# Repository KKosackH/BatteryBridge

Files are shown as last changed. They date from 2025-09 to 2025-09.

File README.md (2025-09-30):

# BatteryBridge  

The **BatteryBridge** is a PowerPath control circuit that ensures the essential electronics on the SwitchSystem PCB remain powered during grid disconnection.  

The SwitchSystem PCB only receives power when the home charger is in **IEC 61851 Control Pilot state C** (charging mode). When transitioning from charging to discharging, the PCB would normally lose power. The BatteryBridge solves this by automatically switching to battery supply, keeping the system running seamlessly.  

---

## Features  
- **Power continuity**: Maintains operation when the grid is disconnected or charger state changes.  
- **Integrated converters**: High-efficiency buck and boost converters for multiple voltage rails.  
- **PowerPath control**: Manages seamless switching between charger and battery.  
- **Battery charging**: Supports onboard Li-ion battery charging.  
- **Multiple outputs**: 3.3 V, 5 V, and 12 V regulated outputs (v1 only included 3.3 V and 5 V).  

---

## Design  
The BatteryBridge PCB consists of three main parts:  
1. High-efficiency buck and boost converters  
2. PowerPath controller  
3. Battery charger  

For the prototype, a **3.7V battery** was used. Long-life battery options are being evaluated with manufacturers to ensure durability of the add-on solution.  

The schematic is organized hierarchically, with the root showing all user-interactable components.  

---

## Operation  
- **State C (charging)**:  
  - The battery charges.  
  - Outputs are disabled (system powered directly from charger).  

- **Other states (discharging / grid disconnected)**:  
  - Outputs are enabled.  
  - Battery supplies regulated 3.3 V, 5 V, and 12 V rails to the SwitchSystem PCB via two JST connectors.  

---

## PCB Images  

### Front Side  
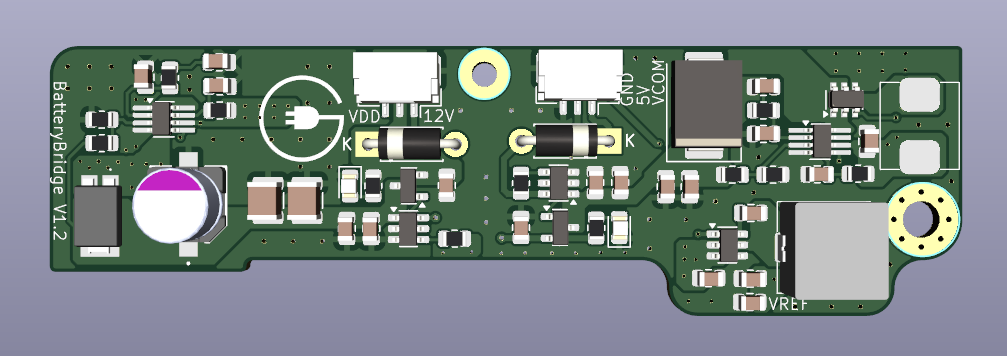
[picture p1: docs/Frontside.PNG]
BatteryBridge Back
  

### Back Side  
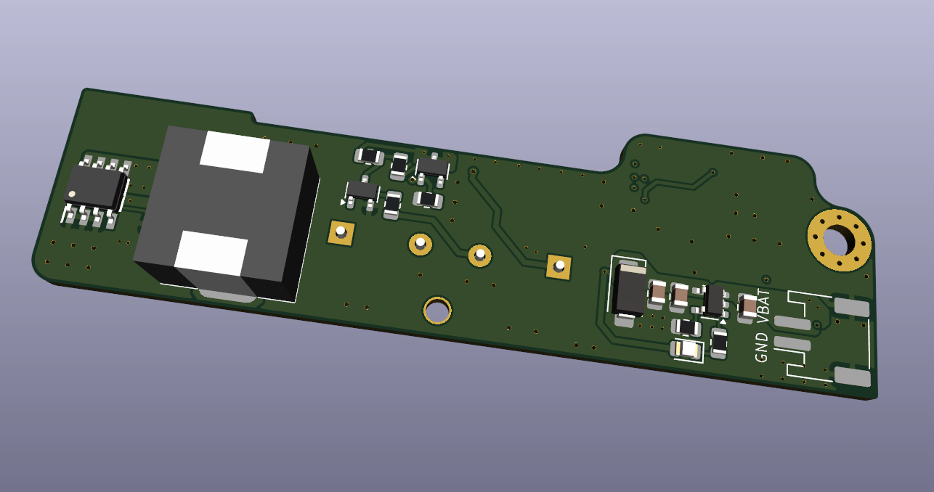
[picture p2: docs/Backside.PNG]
BatteryBridge Front
  

---

## Outputs  
- **3.3 V**  
- **5 V**  
- **12 V**  

These outputs are used primarily to power the Raspberry Pi and essential circuits on the SwitchSystem PCB.

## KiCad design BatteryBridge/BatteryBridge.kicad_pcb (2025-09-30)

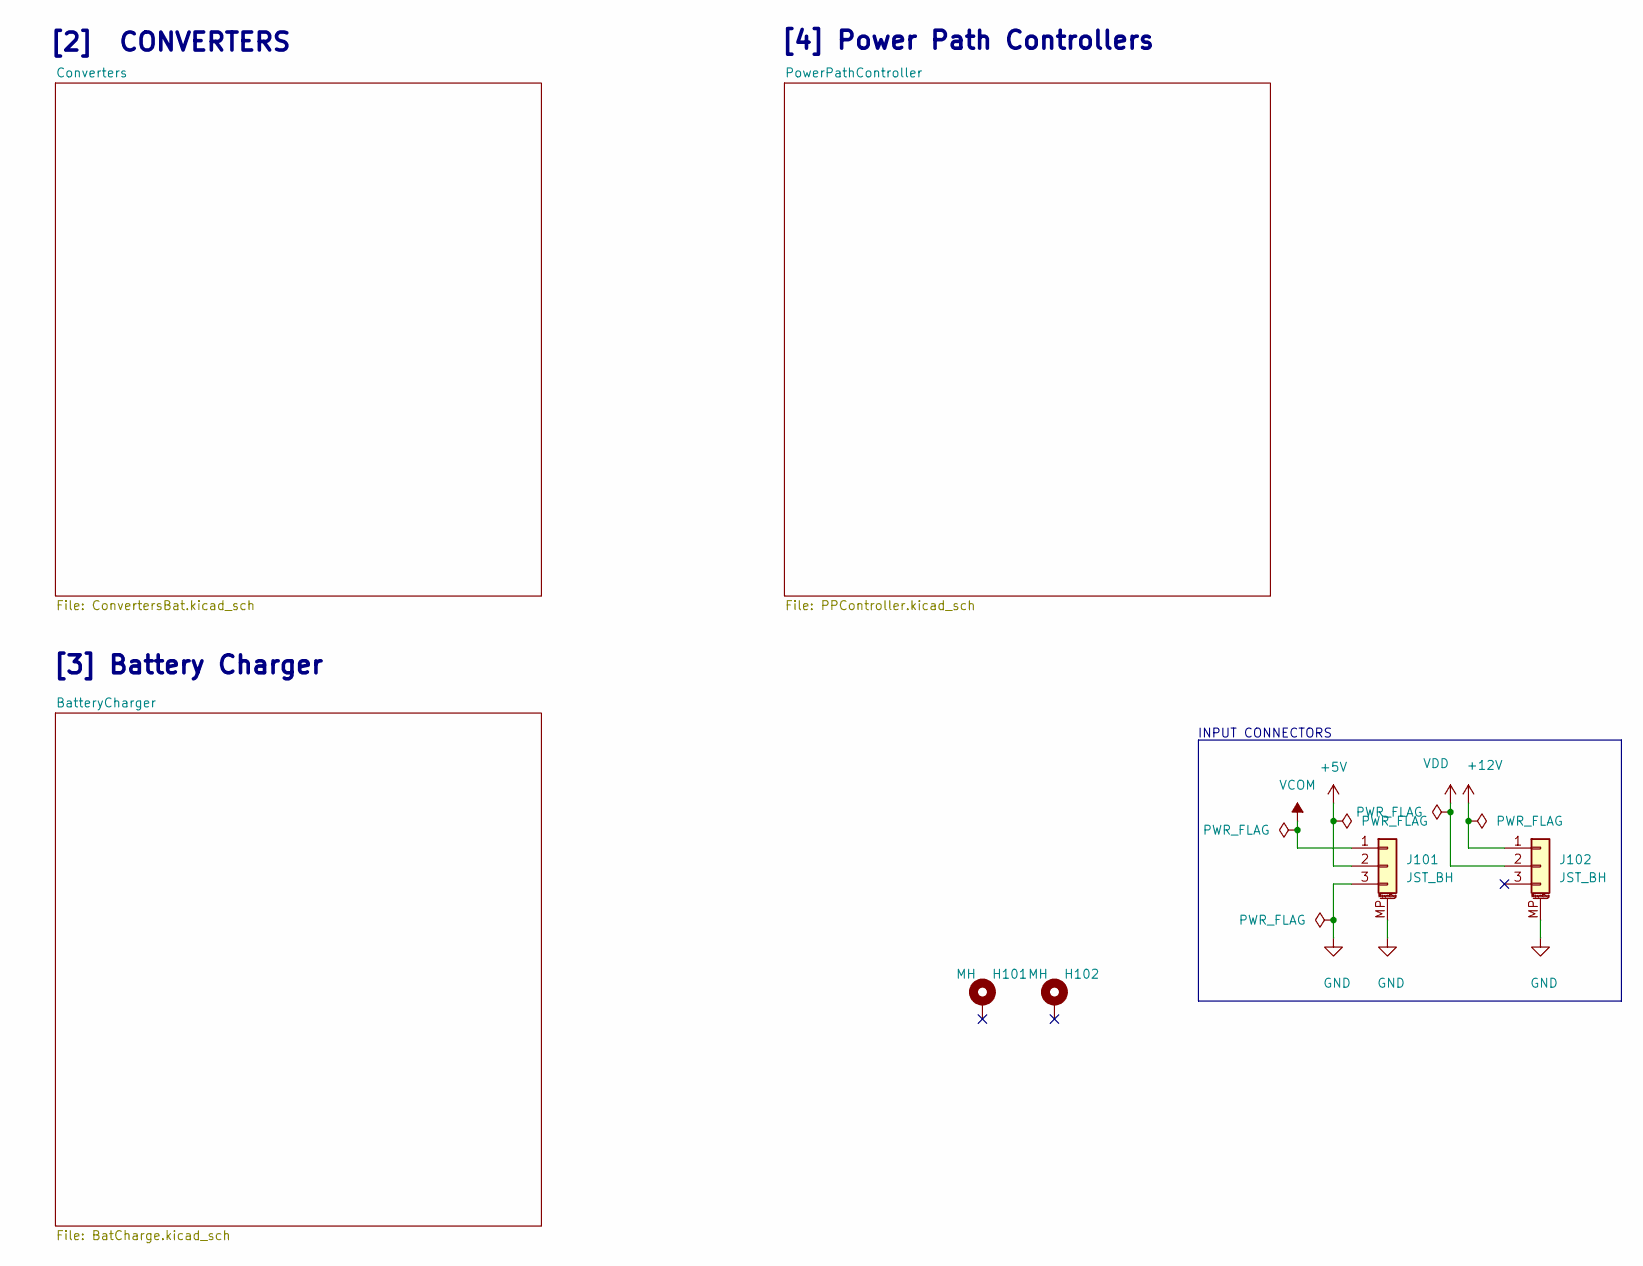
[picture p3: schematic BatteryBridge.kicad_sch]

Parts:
H101: MH; MountingHole_3.2mm_M3_Pad_Via
H102: MH; MountingHole_2.2mm_M2_Pad_TopOnly
J101, J102: JST_BH; JST_GH_SM03B-GHS-TB_1x03-1MP_P1.25mm_Horizontal

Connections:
+5V: J101.2; also elsewhere on the board
+12V: J102.1; also elsewhere on the board
GND: J101.3, J101.MP (MountPin), J102.MP (MountPin); also elsewhere on the board
VCOM: J101.1; also elsewhere on the board
VDD: J102.2; also elsewhere on the board

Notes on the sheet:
INPUT CONNECTORS
[2] CONVERTERS
[3] Battery Charger
[4] Power Path Controllers

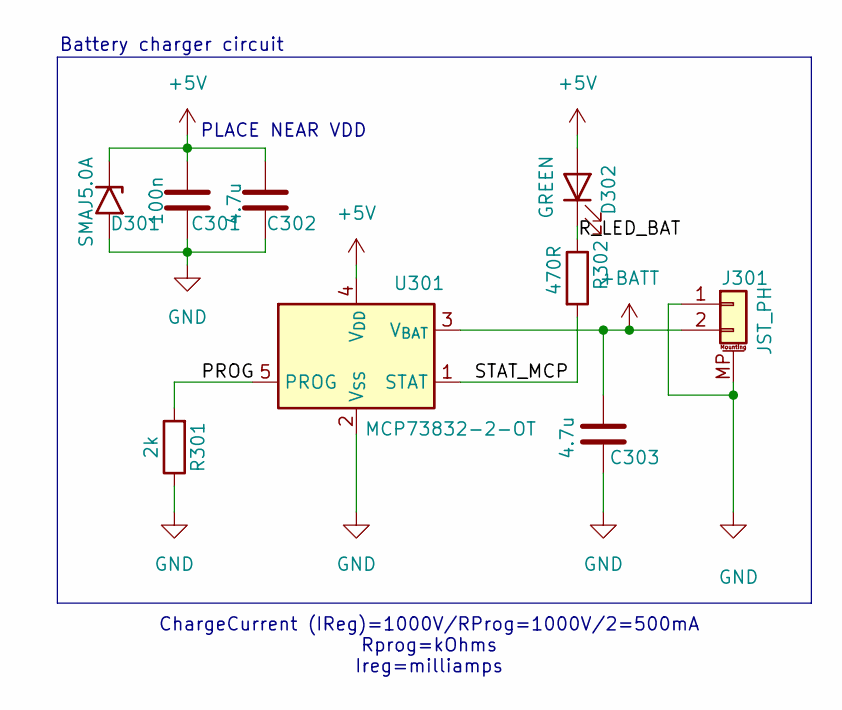
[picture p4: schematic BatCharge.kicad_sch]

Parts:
C301: 100n; C_0805_2012Metric
C302, C303: 4.7u; C_0805_2012Metric
D301: SMAJ5.0A; D_SMA
D302: GREEN; LED_0805_2012Metric
J301: JST_PH; JST_PH_S2B-PH-SM4-TB_1x02-1MP_P2.00mm_Horizontal
R301: 2k; R_0805_2012Metric
R302: 470R; R_0805_2012Metric
U301: MCP73832-2-OT; SOT-23-5

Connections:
+5V: C301.2, C302.2, D301.1 (A1), D302.2 (A), U301.4 (V_{DD}); also elsewhere on the board
+BATT: C303.2, J301.2, U301.3 (V_{BAT}); also elsewhere on the board
/BatteryCharger/PROG: R301.2, U301.5 (PROG)
/BatteryCharger/R_LED_BAT: D302.1 (K), R302.1
/BatteryCharger/STAT_MCP: R302.2, U301.1 (STAT)
GND: C301.1, C302.1, C303.1, D301.2 (A2), J301.1, J301.MP (MountPin), R301.1, U301.2 (V_{SS}); also elsewhere on the board

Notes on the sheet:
Battery charger circuit
PLACE NEAR VDD
ChargeCurrent (IReg)=1000V/RProg=1000V/2=500mA Rprog=kOhms Ireg=milliamps

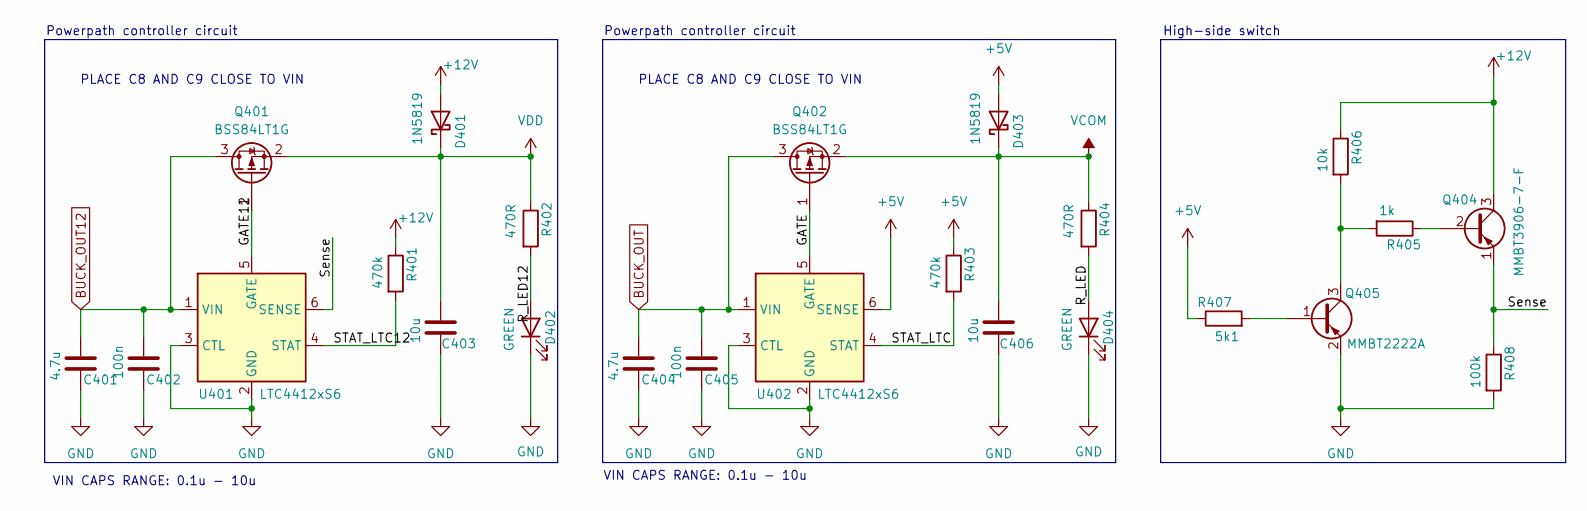
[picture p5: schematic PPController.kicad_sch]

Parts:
C401, C404: 4.7u; C_0805_2012Metric
C402, C405: 100n; C_0805_2012Metric
C403, C406: 10u; C_0805_2012Metric
D401, D403: 1N5819; D_DO-41_SOD81_P7.62mm_Horizontal
D402, D404: GREEN; LED_0805_2012Metric
Q401, Q402: BSS84LT1G; SOT-23
Q404: MMBT3906-7-F; SOT-23-3
Q405: MMBT2222A; SOT-23-3
R401, R403: 470k; R_0805_2012Metric
R402, R404: 470R; R_0805_2012Metric
R405: 1k; R_0805_2012Metric
R406: 10k; R_0805_2012Metric
R407: 5k1; R_0805_2012Metric
R408: 100k; R_0805_2012Metric
U401, U402: LTC4412xS6; TSOT-23-6

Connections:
+5V: D403.2 (A), R403.1, R407.1, U402.6 (SENSE); also elsewhere on the board
+12V: D401.2 (A), Q404.3 (C), R401.1, R406.1; also elsewhere on the board
/PowerPathController/GATE: Q402.1 (G), U402.5 (GATE)
/PowerPathController/GATE12: Q401.1 (G), U401.5 (GATE)
/PowerPathController/R_LED: D404.2 (A), R404.2
/PowerPathController/R_LED12: D402.2 (A), R402.2
/PowerPathController/STAT_LTC: R403.2, U402.4 (STAT)
/PowerPathController/STAT_LTC12: R401.2, U401.4 (STAT)
/PowerPathController/Sense: Q404.1 (E), R408.1, U401.6 (SENSE)
BUCK_OUT: C404.2, C405.2, Q402.3 (D), U402.1 (VIN); also elsewhere on the board
BUCK_OUT12: C401.2, C402.2, Q401.3 (D), U401.1 (VIN); also elsewhere on the board
GND: C401.1, C402.1, C403.2, C404.1, C405.1, C406.2, D402.1 (K), D404.1 (K), Q405.2 (E), R408.2, U401.2 (GND), U401.3 (CTL), U402.2 (GND), U402.3 (CTL); also elsewhere on the board
unnamed: Q404.2 (B), R405.1
unnamed: Q405.1 (B), R407.2
unnamed: Q405.3 (C), R405.2, R406.2
VCOM: C406.1, D403.1 (K), Q402.2 (S), R404.1; also elsewhere on the board
VDD: C403.1, D401.1 (K), Q401.2 (S), R402.1; also elsewhere on the board

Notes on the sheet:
Powerpath controller circuit
PLACE C8 AND C9 CLOSE TO VIN
High-side switch
VIN CAPS RANGE: 0.1u - 10u

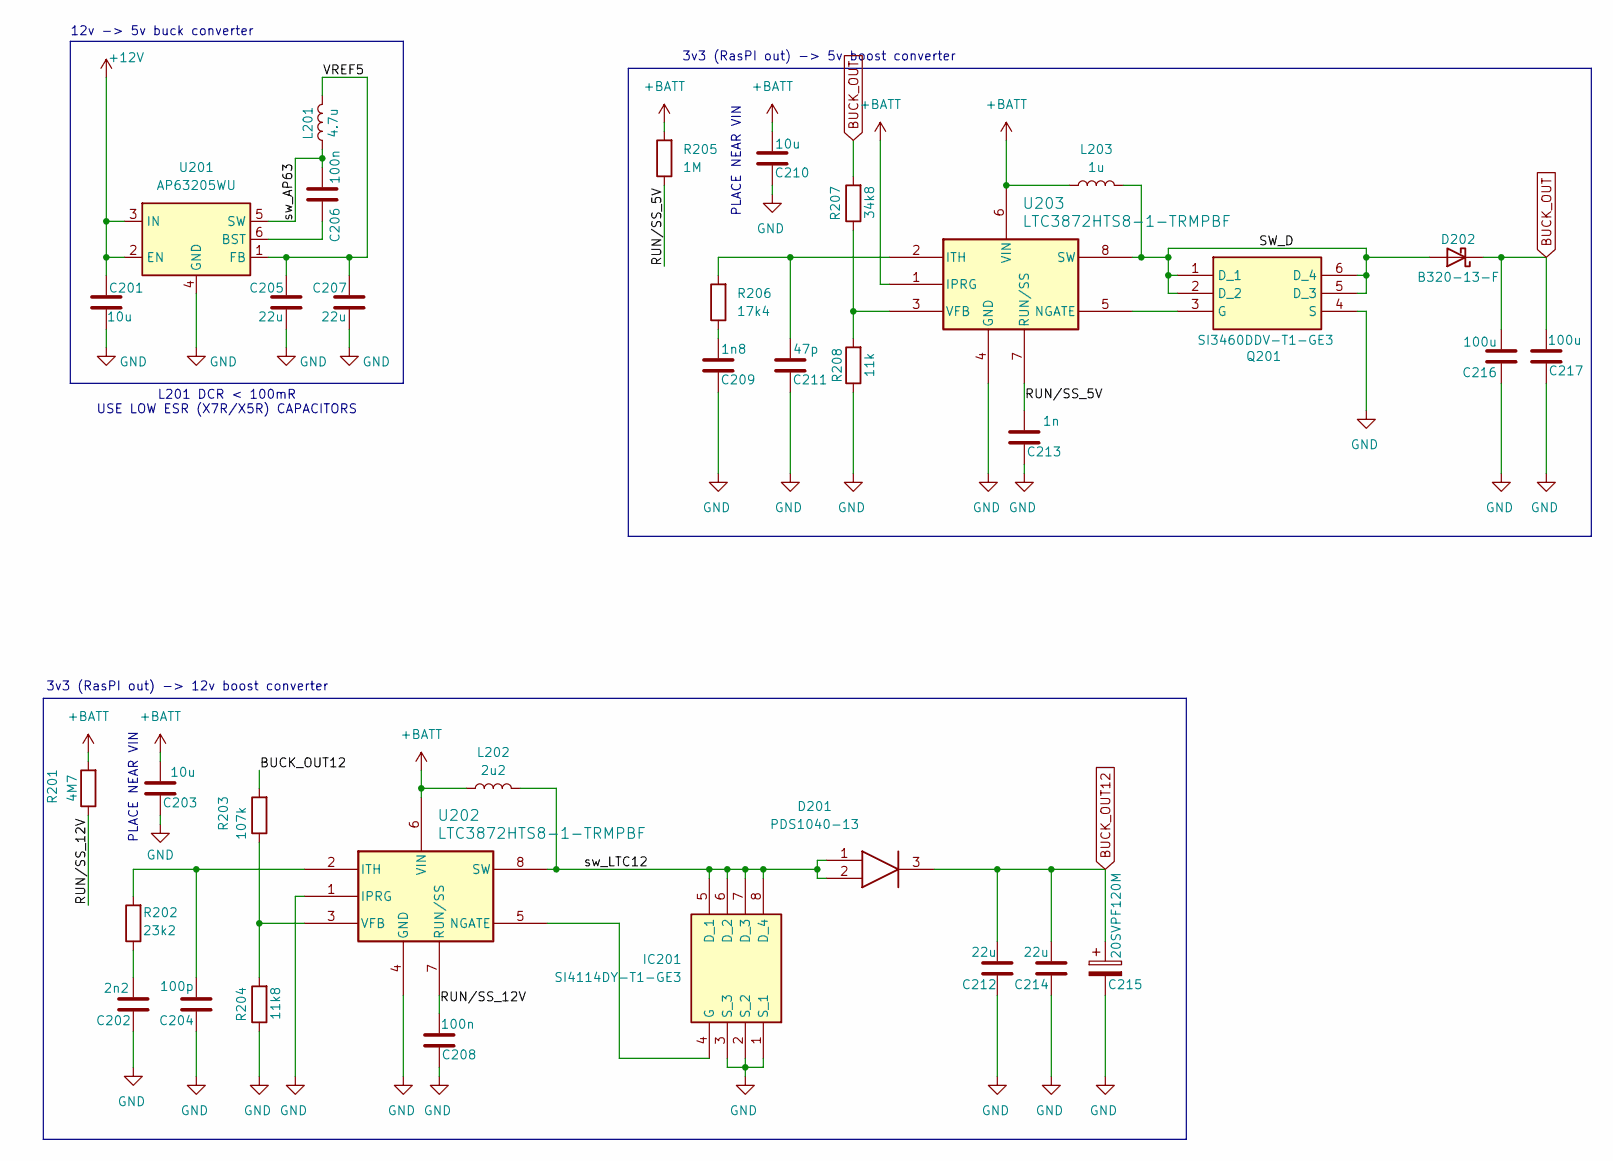
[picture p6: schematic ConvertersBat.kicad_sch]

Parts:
C201, C203, C210: 10u; C_0805_2012Metric
C202: 2n2; C_0805_2012Metric
C204: 100p; C_0805_2012Metric
C205, C207: 22u; C_0805_2012Metric
C206, C208: 100n; C_0805_2012Metric
C209: 1n8; C_0805_2012Metric
C211: 47p; C_0805_2012Metric
C212, C214: 22u; C_1210_3225Metric
C213: 1n; C_0805_2012Metric
C215: 20SVPF120M; 16SVF180M
C216, C217: 100u; C_0805_2012Metric
D201: PDS1040-13; PDS104013; Mouser Part Number 621-PDS1040-13
D202: B320-13-F; D_SMC
IC201: SI4114DY-T1-GE3; SOIC127P600X175-8N; Mouser Part Number 781-SI4114DY-T1-GE3
L201: 4.7u; HCM1A0805-4R7-R
L202: 2u2; DR125-2R2-R
L203: 1u; PA4341.102NLT
Q201: SI3460DDV-T1-GE3; TSOP-6_1.65x3.05mm_P0.95mm; Mouser Part Number 781-SI3460DDV-T1-GE3
R201: 4M7; R_0805_2012Metric
R202: 23k2; R_0805_2012Metric
R203: 107k; R_0805_2012Metric
R204: 11k8; R_0805_2012Metric
R205: 1M; R_0805_2012Metric
R206: 17k4; R_0805_2012Metric
R207: 34k8; R_0805_2012Metric
R208: 11k; R_0805_2012Metric
U201: AP63205WU; TSOT-23-6
U202, U203: LTC3872HTS8-1-TRMPBF; TSOT-23-8_HandSoldering

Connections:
+12V: C201.2, U201.2 (EN), U201.3 (IN); also elsewhere on the board
+BATT: C203.1, C210.1, L202.1, L203.1, R201.2, R205.2, U202.6 (VIN), U203.1 (IPRG), U203.6 (VIN); also elsewhere on the board
/Converters/RUN/SS_5V: C213.1, R205.1, U203.7 (RUN/SS)
/Converters/RUN/SS_12V: C208.1, R201.1, U202.7 (RUN/SS)
/Converters/SW_D: D202.2 (A), L203.2, Q201.1 (D_1), Q201.2 (D_2), Q201.5 (D_3), Q201.6 (D_4), U203.8 (SW)
/Converters/VREF5: C205.2, C207.2, L201.2, U201.1 (FB)
/Converters/sw_AP63: C206.1, L201.1, U201.5 (SW)
/Converters/sw_LTC12: D201.1 (A1), D201.2 (A2), IC201.5 (D_1), IC201.6 (D_2), IC201.7 (D_3), IC201.8 (D_4), L202.2, U202.8 (SW)
BUCK_OUT: C216.1, C217.1, D202.1 (K), R207.2; also elsewhere on the board
BUCK_OUT12: C212.1, C214.1, C215.1, D201.3 (K), R203.2; also elsewhere on the board
GND: C201.1, C202.2, C203.2, C204.2, C205.1, C207.1, C208.2, C209.2, C210.2, C211.2, C212.2, C213.2, C214.2, C215.2, C216.2, C217.2, IC201.1 (S_1), IC201.2 (S_2), IC201.3 (S_3), Q201.4 (S), R204.1, R208.1, U201.4 (GND), U202.1 (IPRG), U202.4 (GND), U203.4 (GND); also elsewhere on the board
unnamed: C202.1, R202.1
unnamed: C209.1, R206.1
unnamed: IC201.4 (G), U202.5 (NGATE)
unnamed: Q201.3 (G), U203.5 (NGATE)
unnamed: C206.2, U201.6 (BST)
unnamed: C204.1, R202.2, U202.2 (ITH)
unnamed: R203.1, R204.2, U202.3 (VFB)
unnamed: C211.1, R206.2, U203.2 (ITH)
unnamed: R207.1, R208.2, U203.3 (VFB)

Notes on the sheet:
12v -> 5v buck converter
PLACE NEAR VIN
3v3 (RasPI out) -> 5v boost converter
L201 DCR < 100mR USE LOW ESR (X7R/X5R) CAPACITORS
3v3 (RasPI out) -> 12v boost converter

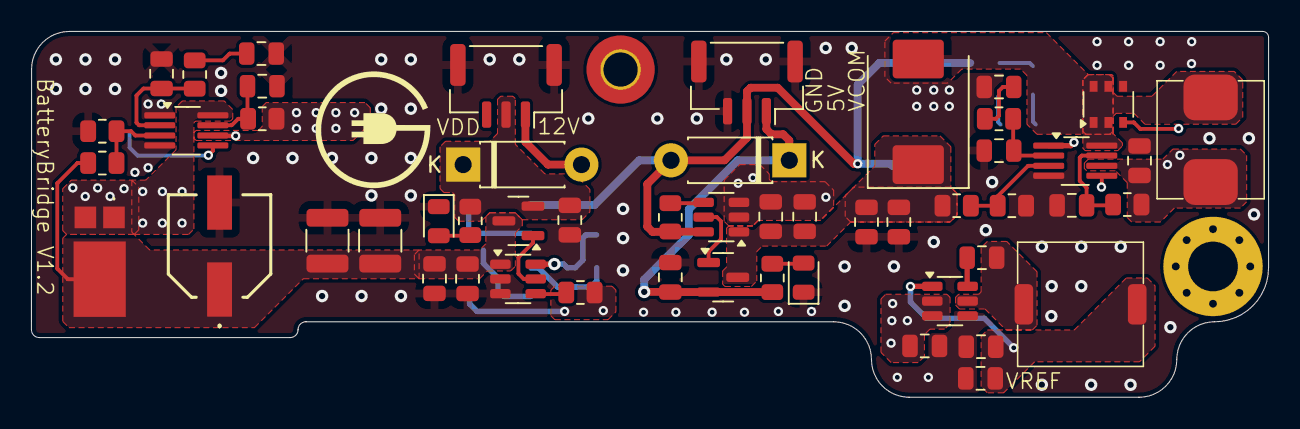
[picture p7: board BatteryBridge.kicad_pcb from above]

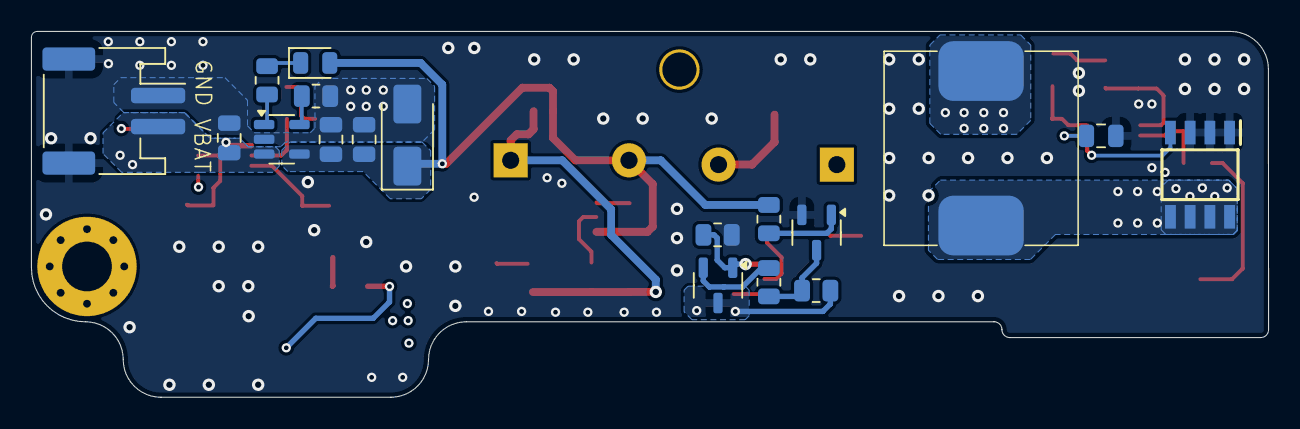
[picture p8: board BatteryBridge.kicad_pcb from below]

Board: 6 copper layers, 79.7 x 23.6 mm, 72 parts (18 on the bottom side), 36 nets.

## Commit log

2024-06-27 First commit, finished V1, needs logo
    [BatteryBridge-B_Cu.gbl, BatteryBridge-B_Mask.gbs, BatteryBridge-B_Paste.gbp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]
2024-10-16 Finished V1.1, added gerbers/drills
    [BatteryBridge-B_Cu.gbl, BatteryBridge-B_Mask.gbs, BatteryBridge-B_Paste.gbp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]
2024-10-18 Finished schematic and component selection
    [BatCharge.kicad_sch, BatteryBridge.kicad_sch, ConvertersBat.kicad_sch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]
2024-10-20 Started layout labtop
    [BatCharge.kicad_sch, BatteryBridge.kicad_pcb, BatteryBridge.kicad_sch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]
2024-10-21 Finished v1.2, added gerbers
    [BatCharge.kicad_sch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]
2025-09-30 Added pictures and updated readme
    [BatteryBridge-B_Cu.gbl, BatteryBridge-B_Mask.gbs, BatteryBridge-B_Paste.gbp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]
